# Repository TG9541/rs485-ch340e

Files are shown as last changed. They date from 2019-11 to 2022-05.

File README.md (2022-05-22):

# RS485-CH340E



I needed a USB-RS485 dongle with reliable automatic direction control but it was impossible to find anything that's both reliable and cheap (not to speak of small). The "budget" cmmercial USB-RS485 dongles "try" to implement direction controll with the host's Tx signal. The timing of such a solution is tricky (and potentially unreliable). A "popular" work-around is using a [questionable "dominant-recessive"](https://hackaday.io/project/167532-modbus-things-with-stm8-eforth/log/168474-finding-the-culprit) approach to RX-TX switching with a "CAN network style" recessive default state. Such a hack is certainly not RS485 compliant and may randomly fail if multiple nodes are connected, the bus cable is long, at higher bit-rates, if the weather changes, or in any combination of that.

Fortunately, the very cheap CH340E provides a true RX/TX direction signal that can be used for controlling an RS485 transceiver with perfect timing. I was surprised that there are still no cheap CH340E based RS485 dongles on the market - so I decided to make one. This repository provides a small CH340E based configurable RS485 or TTL 2/3-wire USB dongle.

If you're "shopping" for ideas how to use this solution down for a mass-market product: it's certainly possible to make solution with a minimal BOM, or one with additional robustness. Feel free to writen me an [issue](https://github.com/TG9541/rs485-ch340e/issues) if you want to learn how.

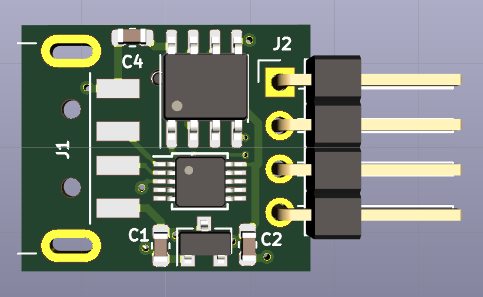
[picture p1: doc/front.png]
front


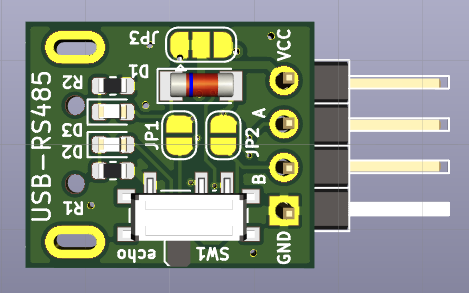
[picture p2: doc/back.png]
back


## PCB
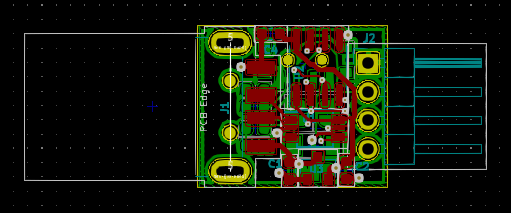
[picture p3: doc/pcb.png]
PCB


## Schematic

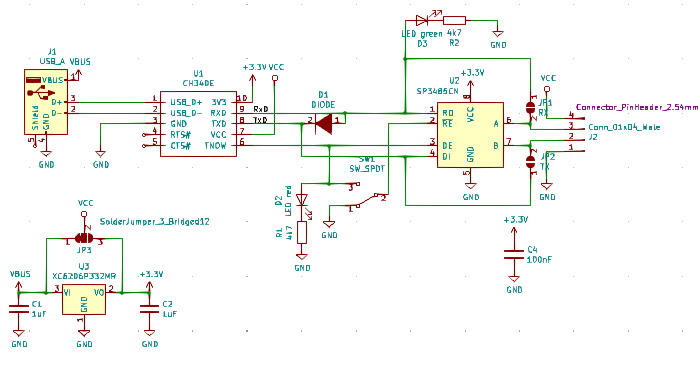
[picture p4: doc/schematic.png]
schematic


The BOM is in the doc folder.

Note: the supply voltage of U1 can be selected with J3. It is either 5V (default) or 3.3V (1-2 open, 2-3 closed). This configuration option has not been tested.

## RS485 configuration:

The built-in CH340E 3.3V LDO can provide a 3.3V supply for the RS485 transceiver which makes populating the linear voltage regulator U3 (XC6206P332MR) optional. For most applications it's better to populate U3 since the maximum number of RS485 nodes that can be connected to the bus might be limited by the current that the internal LDO can provide.

Note: SW1 controlls "TX-RX echo" (pin1-1 closed) or "no echo" (pin2-3 closed, this is standard RS485 functionality). If switching isn't required the pads can be bridged with a bit of solder. Most people won't need switching and in a re-design I would certainly replace SW1 with a jumper.

### Core RS485 configuration (limited fan-out): 
Populate the following:
* front side: U1, U2, C2, C4, J2
* back side: SW1

## Standar RS485 configuration (standard fan-out):
Populate the following:
* front side: U1, U2, U3, C1, C2, C4, J2
* back side: SW1, R1, R2, D2, D3

## RS232-TTL configuration:

The dongle can be configured for 3-wire (full duplex) or 2-wire (half duplex) communication. The 2-wire option can be used for command-response console protocols, e.g., the [half-duplex STM8 eForth configuration](https://github.com/TG9541/stm8ef/wiki/STM8-eForth-Programming-Tools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).

### 3-wire configuration: 
Populate the following:
* front side: U1, C2, C4, J2
* back side: (optional) R1, R2, D2, D3 

Close jumpers J1 (RX, J2.3) and J2 (TX, J2.2) on the back side. 

### 2-wire configuration: 
Populate the following:
* front side: U1, C2, C4, J2
* back side: D1, (optional) R1, R2, D2, D3 

Close jumpers J1 (RX/TX, J2.3) on the back side.

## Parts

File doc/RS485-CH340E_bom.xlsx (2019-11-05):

Source: | /home/thomas/kicad/rs485-ch340e/RS485-CH340E.sch
Date: | Di 05 Nov 2019 20:26:29 CET
Tool: | Eeschema 5.1.4-e60b266~84~ubuntu16.04.1
Generator: | /usr/share/kicad/plugins/bom_csv_grouped_by_value_with_fp.py
Component Count: | 17
Ref | Qnty | Value | Cmp name | Footprint | Description | Vendor
C2, C1, | 2 | 1uF | C | Capacitor_SMD:C_0603_1608Metric | Unpolarized capacitor
C4, | 1 | 100nF | C | Capacitor_SMD:C_0603_1608Metric | Unpolarized capacitor
D1, | 1 | 1N4148 MiniMELF (optional) | DIODE | Diode_SMD:D_MiniMELF | Diode symbol for simulation only. Pin order incompatible with official kicad footprints
D2, | 1 | LED red | LED | LED_SMD:LED_0603_1608Metric | Light emitting diode
D3, | 1 | LED green | LED | LED_SMD:LED_0603_1608Metric | Light emitting diode
J1, | 1 | USB_A | USB_A | Connector_USB:USB_A_CNCTech_1001-011-01101_Horizontal | USB Type A connector
J2, | 1 | Conn_01x04_Male | Conn_01x04_Male | Connector_PinHeader_2.54mm:PinHeader_1x04_P2.54mm_Horizontal | Generic connector, single row, 01x04, script generated (kicad-library-utils/schlib/autogen/connector/)
JP1, | 1 | RX | SolderJumper_2_Open | Jumper:SolderJumper-2_P1.3mm_Open_RoundedPad1.0x1.5mm | Solder Jumper, 2-pole, open
JP2, | 1 | TX | SolderJumper_2_Open | Jumper:SolderJumper-2_P1.3mm_Open_RoundedPad1.0x1.5mm | Solder Jumper, 2-pole, open
JP3, | 1 | SolderJumper_3_Bridged12 | SolderJumper_3_Bridged12 | Jumper:SolderJumper-3_P1.3mm_Bridged12_RoundedPad1.0x1.5mm | 3-pole Solder Jumper, pins 1+2 closed/bridged
R2, R1, | 2 | 4k7 | R | Resistor_SMD:R_0603_1608Metric | Resistor
SW1, | 1 | MSK-12C02 | SW_SPDT | Button_Switch_SMD:SW_SPDT_PCM12 | Switch, single pole double throw
U1, | 1 | CH340E | CH340E | Package_SO:TSSOP-10_3x3mm_P0.5mm
U2, | 1 | SP3485CN (optional) | SP3485CN | Package_SO:SOIC-8_3.9x4.9mm_P1.27mm | 3.3V Low Power Half-Duplex RS-485 Transceiver 10Mbps, SO8
U3, | 1 | XC6206P332MR | XC6206P332MR | Package_TO_SOT_SMD:SOT-23 | Low Quiescent Current LDO Regulator, 3.3V, 200 mA, Vin<=7V, SOT-23

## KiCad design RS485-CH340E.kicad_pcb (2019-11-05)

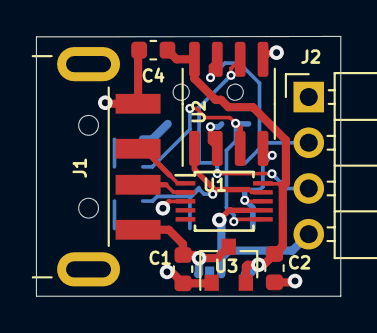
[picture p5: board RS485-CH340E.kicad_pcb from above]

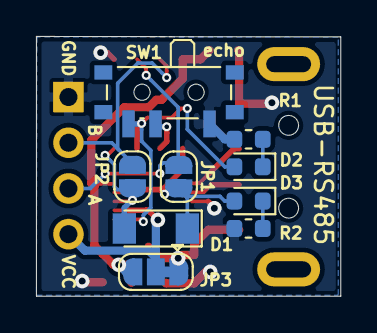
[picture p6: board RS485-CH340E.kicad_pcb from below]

Board: 2 copper layers, 16.9 x 14.4 mm, 17 parts (9 on the bottom side), 14 nets.

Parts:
C1, C2: 1uF; C_0603_1608Metric
C4: 100nF; C_0603_1608Metric
D1: DIODE; D_MiniMELF
D2: LED red; LED_0603_1608Metric
D3: LED green; LED_0603_1608Metric
J1: USB_A; USB_A_CNCTech_1001-011-01101_Horizontal
J2: Conn_01x04_Male; PinHeader_1x04_P2.54mm_Horizontal
JP1: RX; SolderJumper-2_P1.3mm_Open_RoundedPad1.0x1.5mm
JP2: TX; SolderJumper-2_P1.3mm_Open_RoundedPad1.0x1.5mm
JP3: SolderJumper_3_Bridged12; SolderJumper-3_P1.3mm_Bridged12_RoundedPad1.0x1.5mm
R1, R2: 4k7; R_0603_1608Metric
SW1: SW_SPDT; SW_SPDT_PCM12
U1: CH340E; TSSOP-10_3x3mm_P0.5mm
U2: SP3485CN; SOIC-8_3.9x4.9mm_P1.27mm
U3: XC6206P332MR; SOT-23

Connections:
+3V3: C2.1, C4.1, JP3.3, U1.10, U2.8, U3.2
/RxD: D1.1, D3.2, JP1.1, U1.9, U2.1
/TxD: D1.2, JP2.1, U1.8, U2.4
GND: C1.2, C2.2, C4.2, J1.4, J2.1, R1.2, R2.2, SW1.1, U1.3, U2.5, U3.1
unnamed: D2.1, R1.1
unnamed: D2.2, SW1.3, U1.6, U2.3
unnamed: D3.1, R2.1
unnamed: J1.2, U1.2
unnamed: J1.3, U1.1
unnamed: J2.2, JP2.2, U2.7
unnamed: J2.3, JP1.2, U2.6
unnamed: SW1.2, U2.2
VBUS: C1.1, J1.1, JP3.1, U3.3
VCC: J2.4, JP3.2, U1.7

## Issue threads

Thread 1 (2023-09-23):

stm8ef / XY-LPWM

Igor26974, 2023-09-23:
I found a link to your repository for XY-LPWM on the Internet.
I wanted to make an indicator for myself based on PWM XY-LPWM.
I ordered the boards on Aliexpress, but when I received them, it turned out that they had another controller with a worn-out name (in the SOP-16 case).
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

Do you happen to know what controller this is???

TG9541, 2023-09-25:
Hi Igor, it looks like this popular board has received yet another makeover
by someone who was willing to cut 1 or 2 ct cents from the BOM.

There is no easy way to tell what kind of chip that is but it's almost
certainly no STM8 device.

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
